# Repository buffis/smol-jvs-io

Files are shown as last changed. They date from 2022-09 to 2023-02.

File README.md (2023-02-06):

# smol-jvs-io

Smol JVS IO is a scoped down JVS I/O board designed to work as a drop-in replacement for arcade stick PCB's, to allow them to interface with JVS hardware. It is not meant to function as a fully functional JVS IO in terms of functionality.

This hardware and software of this board was forked from [td-io](https://github.com/tdaede/td-io) and then heavily scoped down to fit my needs. The td-io firmware is not directly compatible, due to design shortcuts on this board such as removing the shift registers.

At this point, I suppose not much of the td-io hardware schematic is used here any more. The firmware is still a pretty close fork though.

# Features

* JVS IO board interface as one-player device.
* Brook board compatible 20pin connector for hooking up player 1 stick and buttons.
* Upgradeable firmware

# BOM

Note that earlier versions may miss some of these, or have other component identifiers, but overall should be the same.

- U1 ADM3485EARZ-REEL7 or ST3485EBDR (or some other pin compatible one)
- U2 Raspberry Pi Pico
- Q1 AO3400A (Or any similar mosfet)
- D1 BAV99S,115 
- R1 0805 120ohm
- R2 0805 1k ohm
- J1 USBR-B-S-F-O-TH (Digikey: SAM10873-ND)
- J2 JST PH 1x4
- J3 JST PH 1x4
- J4 2.54mm Pinheader 2x10
- J5 JST XH 1x2

# Stuff intentionally not provided

* Player 2 controls
* Chaining other JVS IO boards
* Video/Audio handling
* Analog controls, Mahjong controls...

# Power

Power can either be provided to the micro USB port of the raspberry pi pico, or through the +5V/GND pins of the board.

# Firmware Updates

Flash the Raspberry Pi Pico with new firmware. Make sure stick is not powered from other sources.

# License

CERN-OHL-W

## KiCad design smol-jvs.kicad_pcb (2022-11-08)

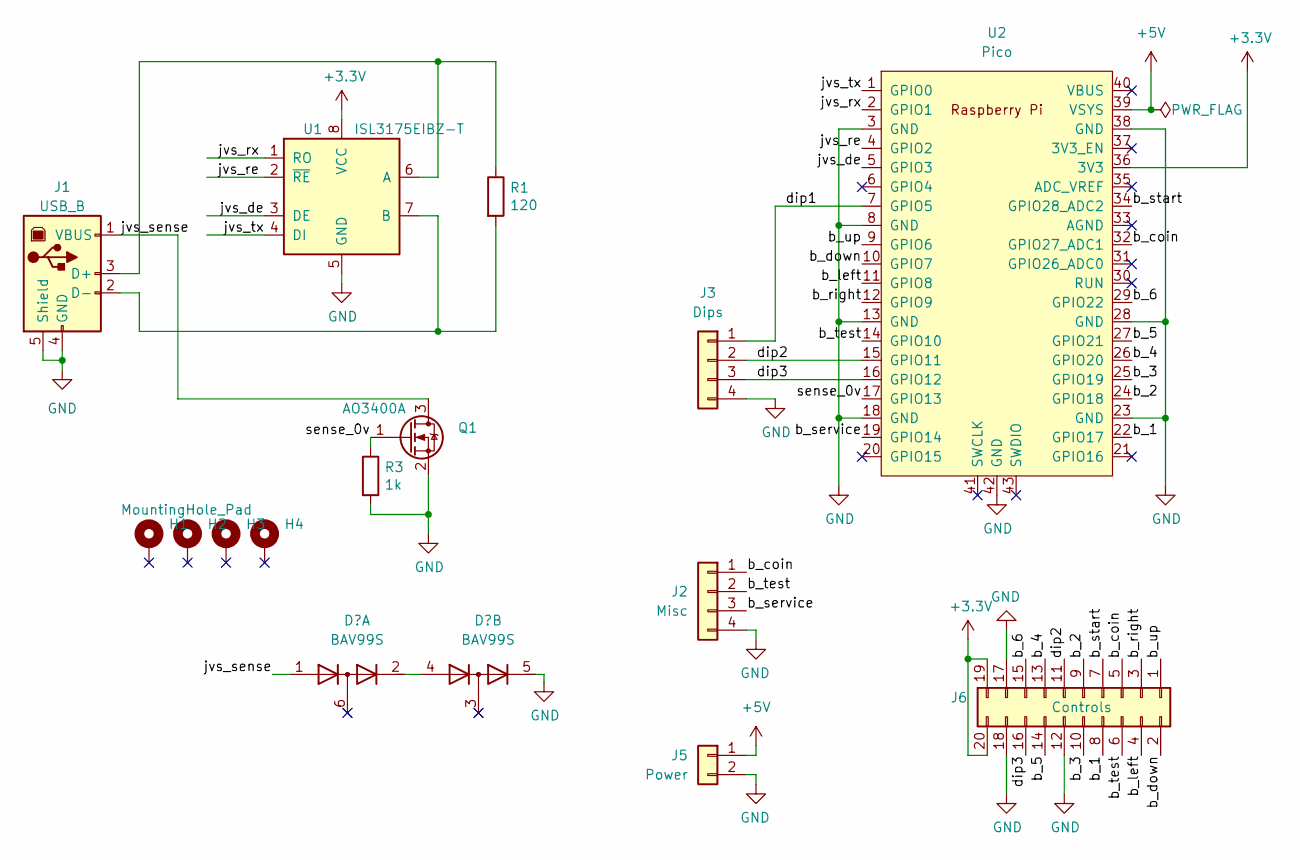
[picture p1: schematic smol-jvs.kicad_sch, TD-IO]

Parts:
H1, H2, H3, H4: MountingHole_Pad; MountingHole_2.5mm_Pad
J1: USB_B; USB_B_OST_USB-B1HSxx_Horizontal; Digikey SAM10873-ND
J2: Misc; JST_PH_B4B-PH-K_1x04_P2.00mm_Vertical
J3: Dips; JST_PH_B4B-PH-K_1x04_P2.00mm_Vertical
J5: Power; JST_XH_B2B-XH-AM_1x02_P2.50mm_Vertical
J6: Controls; PinHeader_2x10_P2.54mm_Vertical
Q1: AO3400A; SOT-23
R1: 120; R_0805_2012Metric; Digikey 13-RT0805FRE07120RLCT-ND
R3: 1k; R_0805_2012Metric; Digikey 311-10.0KCRCT-ND
U1: ISL3175EIBZ-T; SOIC-8_3.9x4.9mm_P1.27mm; Digikey 1016-1150-5-ND
U2: Pico; RPi_Pico_SMD_TH

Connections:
+3V3: J6.19, J6.20, U1.8 (VCC), U2.36 (3V3)
+5V: J5.1, U2.39 (VSYS)
/b_1: J6.8, U2.22 (GPIO17)
/b_2: J6.9, U2.24 (GPIO18)
/b_3: J6.10, U2.25 (GPIO19)
/b_4: J6.13, U2.26 (GPIO20)
/b_5: J6.14, U2.27 (GPIO21)
/b_6: J6.15, U2.29 (GPIO22)
/b_coin: J2.1, J6.5, U2.32 (GPIO27_ADC1)
/b_down: J6.2, U2.10 (GPIO7)
/b_left: J6.4, U2.11 (GPIO8)
/b_right: J6.3, U2.12 (GPIO9)
/b_service: J2.3, U2.19 (GPIO14)
/b_start: J6.7, U2.34 (GPIO28_ADC2)
/b_test: J2.2, J6.6, U2.14 (GPIO10)
/b_up: J6.1, U2.9 (GPIO6)
/dip1: J3.1, U2.7 (GPIO5)
/dip2: J3.2, J6.11, U2.15 (GPIO11)
/dip3: J3.3, J6.16, U2.16 (GPIO12)
/jvs_de: U1.3 (DE), U2.5 (GPIO3)
/jvs_re: U1.2 (~RE), U2.4 (GPIO2)
/jvs_rx: U1.1 (RO), U2.2 (GPIO1)
/jvs_sense: J1.1 (VBUS), Q1.3 (D); also elsewhere on the board
/jvs_tx: U1.4 (DI), U2.1 (GPIO0)
/sense_0v: Q1.1 (G), R3.1, U2.17 (GPIO13)
GND: J1.4 (GND), J1.5 (Shield), J2.4, J3.4, J5.2, J6.12, J6.17, J6.18, Q1.2 (S), R3.2, U1.5 (GND), U2.3 (GND), U2.8 (GND), U2.13 (GND), U2.18 (GND), U2.23 (GND), U2.28 (GND), U2.38 (GND), U2.42 (GND); also elsewhere on the board
unnamed: J1.2 (D-), R1.2, U1.7 (B)
unnamed: J1.3 (D+), R1.1, U1.6 (A)

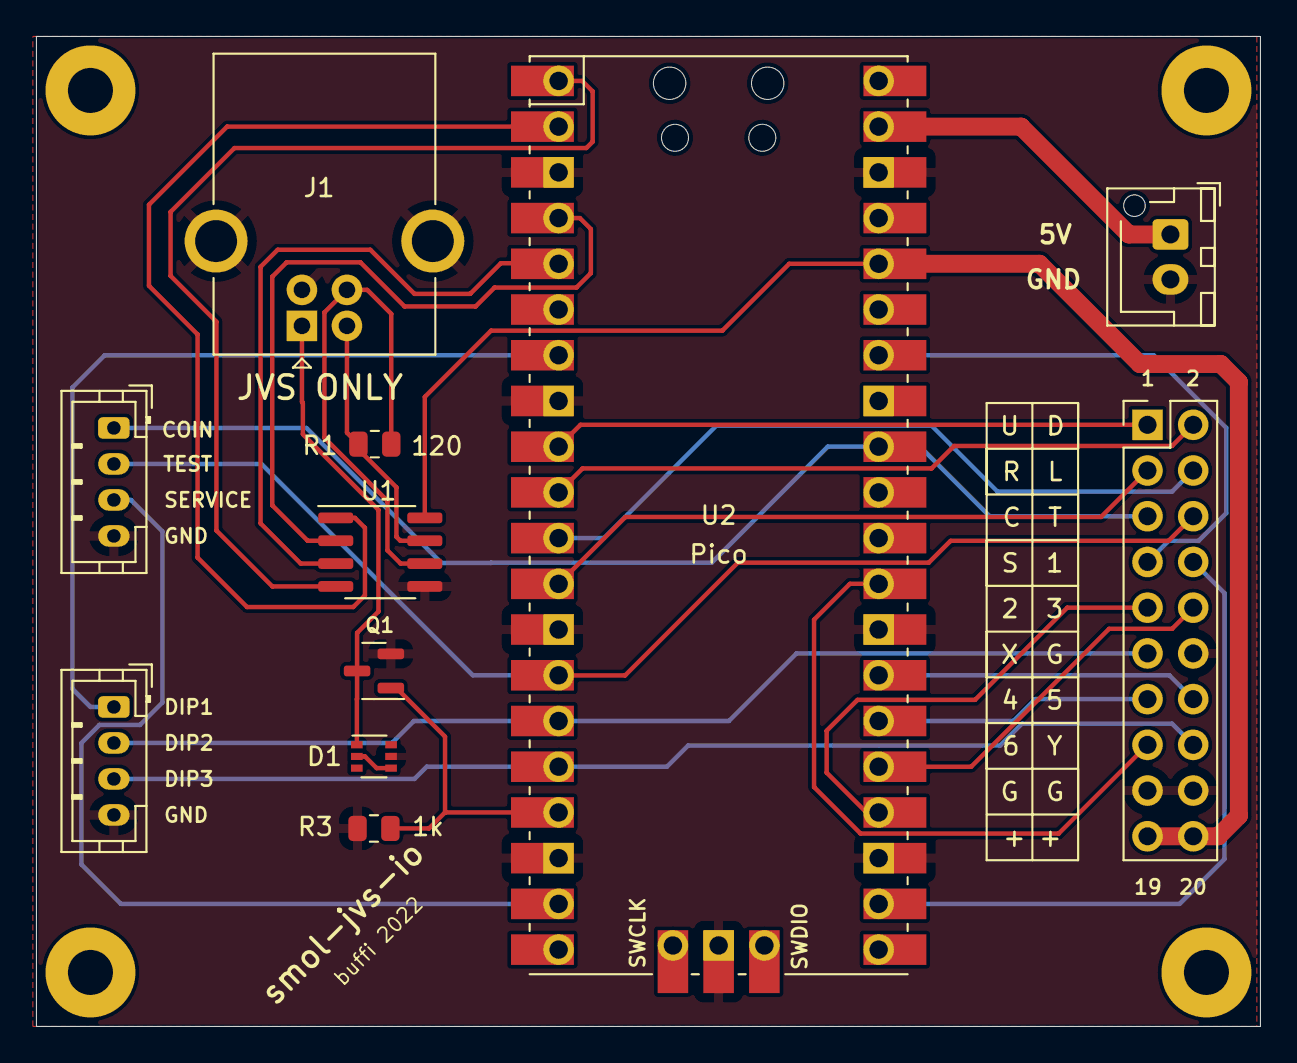
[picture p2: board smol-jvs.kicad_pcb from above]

Board: 2 copper layers, 68.0 x 55.0 mm, 15 parts (0 on the bottom side), 29 nets.

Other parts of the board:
D1: BAV99S; SOT-363_SC-70-6

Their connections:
/jvs_sense: D1.1 (A1); also elsewhere on the board
GND: D1.5 (K4); also elsewhere on the board
unnamed: D1.2 (K2), D1.4 (A3)

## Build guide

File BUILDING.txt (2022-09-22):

# In PowerShell
cd build
cmake -G "NMake Makefiles" ..
nmake

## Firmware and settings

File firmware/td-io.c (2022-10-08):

// Adapted from the https://github.com/tdaede/td-io firmware but scoped down.

#include <stdio.h>
#include "pico/stdlib.h"
#include "hardware/adc.h"
#include <string.h>

const uint PIN_JVS_RE = 2;
const uint PIN_JVS_DE = 3;

const uint PIN_JVS_SENSE_0V = 13;

const uint PIN_JVS_TERMINATION = 15; // TODO: Remove.

const uint PIN_LED_ENUMERATED = PICO_DEFAULT_LED_PIN;
const uint PIN_DIP1 = 11;
const uint PIN_DIP2 = 12;
const uint PIN_DIP3 = 15;

// New pins for direct inputs.
const uint PIN_BTN_TEST = 10;
const uint PIN_BTN_SERVICE = 14;
const uint PIN_BTN_COIN = 27;
const uint PIN_BTN_START = 28;
const uint PIN_JOY_UP = 6;
const uint PIN_JOY_DOWN = 7;
const uint PIN_JOY_LEFT = 8;
const uint PIN_JOY_RIGHT = 9;
const uint PIN_BTN_1 = 17;
const uint PIN_BTN_2 = 18;
const uint PIN_BTN_3 = 19;
const uint PIN_BTN_4 = 20;
const uint PIN_BTN_5 = 21;
const uint PIN_BTN_6 = 22;

const uint8_t JVS_STATUS_GOOD = 1;
const uint8_t JVS_STATUS_UNKNOWN_COMMAND = 2;
const uint8_t JVS_STATUS_CHECKSUM_ERROR = 3;
const uint8_t JVS_STATUS_OVERFLOW = 4;

const uint8_t JVS_REPORT_GOOD = 1;
const uint8_t JVS_REPORT_PARAMETER_INVALID = 3;

const uint8_t JVS_MAX_LEN = 253; // minus two for status and checksum

// global state
uint8_t our_address = 0;
uint64_t last_process_coin = 0;
// signed for underflow checks
int16_t coin_count_p1 = 0;
int16_t coin_count_p2 = 0;
uint8_t prev_coin_p1 = 0;
uint8_t prev_coin_p2 = 0;

#define SR_P1_3 7
#define SR_P2_3 6
#define SR_P1_4 5
#define SR_P2_4 4
#define SR_P1_5 3
#define SR_P2_5 2
#define SR_P1_6 1
#define SR_P2_6 0
#define SR_P1_LEFT 15
#define SR_P2_LEFT 14
#define SR_P1_RIGHT 13
#define SR_P2_RIGHT 12
#define SR_P1_1 11
#define SR_P2_1 10
#define SR_P1_2 9
#define SR_P2_2 8
#define SR_C1 23
#define SR_C2 22
#define SR_P1_START 21
#define SR_P2_START 20
#define SR_P1_UP 19
#define SR_P2_UP 18
#define SR_P1_DOWN 17
#define SR_P2_DOWN 16
#define SR_SERVICE 31
#define SR_TEST 30
#define SR_TILT 29

const uint8_t JVS_COMM_VER = 0x10;
const char id_str[] = "BUFFI;smol-jvs;v1.0;https://github.com/buffis";

const uint8_t input_desc_1coin[] = {
    0x01, 2, 12, 0,
    0x02, 1, 0, 0,
    0x00
};

const uint8_t input_desc_2coin[] = {
    0x01, 2, 12, 0,
    0x02, 2, 0, 0,
    0x00
};

void jvs_sync() {
    uart_putc(uart0, 0xe0);
}

uint8_t jvs_getc() {
    uint8_t c = uart_getc(uart0);
    if (c == 0xd0) {
        c = uart_getc(uart0);
        return c + 1;
    } else {
        return c;
    }
}

void jvs_putc(uint8_t c) {
    if (c == 0xe0) {
        uart_putc(uart0, 0xd0);
        uart_putc(uart0, 0xdf);
    } else if (c == 0xd0) {
        uart_putc(uart0, 0xd0);
        uart_putc(uart0, 0xcf);
    } else {
        uart_putc(uart0, c);
    }
}

void start_transmit() {
    gpio_put(PIN_JVS_RE, 1); // disable receive
    busy_wait_us_32(200);    // 200us min for exa compat
    gpio_put(PIN_JVS_DE, 1); // enable transmitter
}

void stop_transmit() {
    uart_tx_wait_blocking(uart0);
    gpio_put(PIN_JVS_DE, 0); // disable transmitter
    gpio_put(PIN_JVS_RE, 0); // enable receiver
}

void send_message(uint8_t status, uint8_t* m, uint8_t msg_len) {
    start_transmit();
    jvs_sync();
    uint8_t checksum = 0;
    jvs_putc(0);
    checksum += 0;
    jvs_putc(msg_len + 2);
    checksum += msg_len + 2;
    jvs_putc(status);
    checksum += status;
    for (int i = 0; i < msg_len; i++) {
        jvs_putc(m[i]);
        checksum += m[i];
    }
    jvs_putc(checksum);
    stop_transmit();
}

uint32_t read_switches() {
    uint32_t switches = 0;
    switches |= (!gpio_get(PIN_BTN_TEST)) << SR_TEST;
    switches |= (!gpio_get(PIN_BTN_COIN)) << SR_C1;
    switches |= (!gpio_get(PIN_BTN_SERVICE)) << SR_SERVICE;
    switches |= (!gpio_get(PIN_BTN_START)) << SR_P1_START;
    switches |= (!gpio_get(PIN_JOY_UP)) << SR_P1_UP;
    switches |= (!gpio_get(PIN_JOY_DOWN)) << SR_P1_DOWN;
    switches |= (!gpio_get(PIN_JOY_LEFT)) << SR_P1_LEFT;
    switches |= (!gpio_get(PIN_JOY_RIGHT)) << SR_P1_RIGHT;
    switches |= (!gpio_get(PIN_BTN_1)) << SR_P1_1;
    switches |= (!gpio_get(PIN_BTN_2)) << SR_P1_2;
    switches |= (!gpio_get(PIN_BTN_3)) << SR_P1_3;
    switches |= (!gpio_get(PIN_BTN_4)) << SR_P1_4;
    switches |= (!gpio_get(PIN_BTN_5)) << SR_P1_5;
    switches |= (!gpio_get(PIN_BTN_6)) << SR_P1_6;
    return switches;
}

// call periodically with switch read to check level changes of coin input
void process_coin(uint32_t switches) {
    if ((switches >> SR_C1 & 1) && !prev_coin_p1) {
        coin_count_p1++;
        if (coin_count_p1 > 16383) {
            coin_count_p1 = 16383;
        }
    }
    if ((switches >> SR_C2 & 1) && !prev_coin_p2) {
        coin_count_p2++;
        if (coin_count_p2 > 16383) {
            coin_count_p2 = 16383;
        }
    }
    prev_coin_p1 = switches >> SR_C1 & 1;
    prev_coin_p2 = switches >> SR_C2 & 1;
}

int main() {
    stdio_init_all();
    uart_init(uart0, 115200);
    uart_set_translate_crlf(uart0, false);
    gpio_set_function(0, GPIO_FUNC_UART);
    gpio_set_function(1, GPIO_FUNC_UART);
    gpio_init(PIN_JVS_RE);
    gpio_put(PIN_JVS_RE, 0); // enable receiver
    gpio_set_dir(PIN_JVS_RE, GPIO_OUT);
    gpio_init(PIN_JVS_DE);
    gpio_put(PIN_JVS_DE, 0); //disable transmitter
    gpio_set_dir(PIN_JVS_DE, GPIO_OUT);
    gpio_init(PIN_JVS_SENSE_0V);
    gpio_put(PIN_JVS_SENSE_0V, 0);
    gpio_set_dir(PIN_JVS_SENSE_0V, GPIO_OUT);
    gpio_init(PIN_JVS_TERMINATION);
    gpio_put(PIN_JVS_TERMINATION, 1); // disable termination by default
    gpio_set_dir(PIN_JVS_TERMINATION, GPIO_OUT);

    // ui
    gpio_init(PIN_LED_ENUMERATED);
    gpio_put(PIN_LED_ENUMERATED, 0);
    gpio_set_dir(PIN_LED_ENUMERATED, GPIO_OUT);
    gpio_init(PIN_DIP1);
    gpio_set_dir(PIN_DIP1, GPIO_IN);
    gpio_pull_up(PIN_DIP1);

    // Control inputs
    gpio_init(PIN_BTN_TEST);
    gpio_init(PIN_BTN_SERVICE);
    gpio_init(PIN_BTN_COIN);
    gpio_init(PIN_BTN_START);
    gpio_init(PIN_JOY_UP);
    gpio_init(PIN_JOY_DOWN);
    gpio_init(PIN_JOY_LEFT);
    gpio_init(PIN_JOY_RIGHT);
    gpio_init(PIN_BTN_1);
    gpio_init(PIN_BTN_2);
    gpio_init(PIN_BTN_3);
    gpio_init(PIN_BTN_4);
    gpio_init(PIN_BTN_5);
    gpio_init(PIN_BTN_6);
    gpio_set_dir(PIN_BTN_TEST, GPIO_IN);
    gpio_set_dir(PIN_BTN_SERVICE, GPIO_IN);
    gpio_set_dir(PIN_BTN_COIN, GPIO_IN);
    gpio_set_dir(PIN_BTN_START, GPIO_IN);
    gpio_set_dir(PIN_JOY_UP, GPIO_IN);
    gpio_set_dir(PIN_JOY_DOWN, GPIO_IN);
    gpio_set_dir(PIN_JOY_LEFT, GPIO_IN);
    gpio_set_dir(PIN_JOY_RIGHT, GPIO_IN);
    gpio_set_dir(PIN_BTN_1, GPIO_IN);
    gpio_set_dir(PIN_BTN_2, GPIO_IN);
    gpio_set_dir(PIN_BTN_3, GPIO_IN);
    gpio_set_dir(PIN_BTN_4, GPIO_IN);
    gpio_set_dir(PIN_BTN_5, GPIO_IN);
    gpio_set_dir(PIN_BTN_6, GPIO_IN);
    gpio_pull_up(PIN_BTN_TEST);
    gpio_pull_up(PIN_BTN_SERVICE);
    gpio_pull_up(PIN_BTN_COIN);
    gpio_pull_up(PIN_BTN_START);
    gpio_pull_up(PIN_JOY_UP);
    gpio_pull_up(PIN_JOY_DOWN);
    gpio_pull_up(PIN_JOY_LEFT);
    gpio_pull_up(PIN_JOY_RIGHT);
    gpio_pull_up(PIN_BTN_1);
    gpio_pull_up(PIN_BTN_2);
    gpio_pull_up(PIN_BTN_3);
    gpio_pull_up(PIN_BTN_4);
    gpio_pull_up(PIN_BTN_5);
    gpio_pull_up(PIN_BTN_6);

    gpio_put(PIN_JVS_TERMINATION, 0);

    while (true) {
        const uint64_t now = time_us_64();
        if ((now - last_process_coin) > 20000) {
            uint32_t switches = read_switches();
            process_coin(switches);
            last_process_coin = now;
        }

        if (uart_is_readable(uart0) && uart_getc(uart0) == 0xe0) {
            uint8_t our_checksum = 0;
            uint8_t node_num = jvs_getc();
            if (!((node_num == 0xff) || ((our_address == node_num) && (our_address != 0)))) {
                continue;
            }
            our_checksum += node_num;
            uint8_t length = jvs_getc();
            our_checksum += length;
            uint8_t msg_length = length - 1;
            uint8_t message[256];
            for (int i = 0; i < msg_length; i++) {
                uint8_t c = jvs_getc();
                our_checksum += c;
                message[i] = c;
            }
            uint8_t msg_send[256*2]; // a few bytes to spare for easier overflow checking
            int o = 0;
            uint8_t status = JVS_STATUS_GOOD;
            uint8_t their_checksum = jvs_getc();
            if (our_checksum == their_checksum) {
                int i = 0;
                while (i < msg_length) {
                    if ((msg_length - i) >= 2 && message[i] == 0xf0 && message[i+1] == 0xd9) {
                        printf("N: %02x Reset\n", node_num);
                        our_address = 0;
                        gpio_put(PIN_JVS_SENSE_0V, 0);
                        gpio_put(PIN_LED_ENUMERATED, 0);
                        i += 2;
                    } else if ((msg_length - i) >= 2 && message[i] == 0xf1) {
                        uint8_t node_id = message[i+1];
                        i += 2;
                        printf("Assign node id N: %02x\n", node_id);
                        if (our_address == 0) {
                            printf("Assigning our address\n");
                            our_address = node_id;
                            msg_send[o] = JVS_REPORT_GOOD;
                            o++;
                            gpio_put(PIN_JVS_SENSE_0V, 1);
                            gpio_put(PIN_LED_ENUMERATED, 1);
                        } else {
                            printf("We are not currently last in the chain, skipping assignment\n");
                        }
                    } else if ((msg_length - i) >= 1 && message[i] == 0x10) {
                        i++;
                        printf("Got ID code request\n");
                        msg_send[o] = JVS_REPORT_GOOD;
                        o++;
                        strcpy((char*)&msg_send[o], id_str);
                        o += strlen(id_str) + 1;
                    } else if ((msg_length - i) >= 1 && message[i] == 0x11) {
                        i++;
                        printf("Got revision request\n");
                        msg_send[o] = JVS_REPORT_GOOD;
                        o++;
                        msg_send[o] = 0x13;
                        o++;
                    } else if ((msg_length - i) >= 1 && message[i] == 0x12) {
                        i++;
                        printf("Got video revision request\n");
                        msg_send[o] = JVS_REPORT_GOOD;
                        o++;
                        msg_send[o] = 0x30;
                        o++;
                    } else if ((msg_length - i) >= 1 && message[i] == 0x13) {
                        i++;
                        printf("Got comm revision request\n");
                        msg_send[o] = JVS_REPORT_GOOD;
                        o++;
                        msg_send[o] = JVS_COMM_VER;
                        o++;
                    } else if ((msg_length - i) >= 1 && message[i] == 0x14) {
                        i++;
                        printf("Got input descriptor request\n");
                        msg_send[o] = JVS_REPORT_GOOD;
                        o++;
                        if (!gpio_get(PIN_DIP1)) {
                            memcpy(&msg_send[o], input_desc_1coin, sizeof(input_desc_1coin));
                            o += sizeof(input_desc_1coin);
                        } else {
                            memcpy(&msg_send[o], input_desc_2coin, sizeof(input_desc_2coin));                        o += sizeof(input_desc_2coin);
                        }
                    } else if ((msg_length - i) >= 1 && message[i] == 0x15) {
                        i++;
                        printf("Got main board ID: ");
                        while (i < msg_length) {
                            char c = message[i];
                            i++;
                            if (c == 0) break;
                            putchar(message[i]);
                        }
                        printf("\n");
                        msg_send[o] = JVS_REPORT_GOOD;
                        o++;
                    } else if ((msg_length - i) >= 3 && message[i] == 0x20) {
                        int num_players = message[i+1];
                        int bytes_per_player = message[i+2];
                        i += 3;
                        if (o + num_players*bytes_per_player >= JVS_MAX_LEN) {
                            printf("JVS response overflow!\n");
                            status = JVS_STATUS_OVERFLOW;
                            break;
                        }
                        msg_send[o] = JVS_REPORT_GOOD;
                        o++;
                        uint32_t switches = read_switches();
                        if ((now - last_process_coin) > 12000) {
                            process_coin(switches);
                            last_process_coin = now;
                        }
                        // Cool stuff here.
                        msg_send[o] = !gpio_get(PIN_BTN_TEST) << 7;
                        o++;
                        //printf("Got switch request for %02x players\n", num_players);
                        for (int player = 0; player < num_players; player++) {
                            for (int byte = 0; byte < bytes_per_player; byte++) {
                                uint8_t b = 0;
                                if ((player == 0) && (byte == 0)) {
                                    b = ((switches >> SR_P1_2) & 1) << 0
                                        | ((switches >> SR_P1_1) & 1) << 1
                                        | ((switches >> SR_P1_RIGHT) & 1) << 2
                                        | ((switches >> SR_P1_LEFT) & 1) << 3
                                        | ((switches >> SR_P1_DOWN) & 1) << 4
                                        | ((switches >> SR_P1_UP) & 1) << 5
                                        | ((switches >> SR_SERVICE) & 1) << 6
                                        | ((switches >> SR_P1_START) & 1) << 7;
                                } else if ((player == 0) && (byte == 1)) {
                                    b = ((switches >> SR_P1_6) & 1) << 4
                                        | ((switches >> SR_P1_5) & 1) << 5
                                        | ((switches >> SR_P1_4) & 1) << 6
                                        | ((switches >> SR_P1_3) & 1) << 7;
                                } else if ((player == 1) && (byte == 0)) {
                                    b = ((switches >> SR_P2_2) & 1) << 0
                                        | ((switches >> SR_P2_1) & 1) << 1
                                        | ((switches >> SR_P2_RIGHT) & 1) << 2
                                        | ((switches >> SR_P2_LEFT) & 1) << 3
                                        | ((switches >> SR_P2_DOWN) & 1) << 4
                                        | ((switches >> SR_P2_UP) & 1) << 5
                                        | ((switches >> SR_P2_START) & 1) << 7;
                                } else if ((player == 1) && (byte == 1)) {
                                    b = ((switches >> SR_P2_6) & 1) << 4
                                        | ((switches >> SR_P2_5) & 1) << 5
                                        | ((switches >> SR_P2_4) & 1) << 6
                                        | ((switches >> SR_P2_3) & 1) << 7;
                                }
                                msg_send[o] = b;
                                o++;
                            }
                        }
                    } else if ((msg_length - i) >= 2 && message[i] == 0x21) {
                        int slots = message[i+1];
                        i += 2;
                        if (o + slots*2 >= JVS_MAX_LEN) {
                            printf("JVS response overflow!\n");
                            status = JVS_STATUS_OVERFLOW;
                            break;
                        }
                        msg_send[o] = JVS_REPORT_GOOD;
                        o++;
                        //printf("Got coin slot request for %02x slots\n", slots);
                        for (int slot = 0; slot < slots; slot++) {
                            if (slot == 0) {
                                msg_send[o] = coin_count_p1 >> 8;
                                msg_send[o+1] = coin_count_p1 & 0xFF;
                            } else if (slot == 1) {
                                msg_send[o] = coin_count_p2 >> 8;
                                msg_send[o+1] = coin_count_p2 & 0xFF;
                            } else {
                                msg_send[o] = 0x80;
                                msg_send[o+1] = 0x00;
                            }
                            o += 2;
                        }
                    } else if ((msg_length - i) >= 4 && message[i] == 0x30) {
                        uint8_t slot = message[i+1];
                        uint16_t amount = (message[i+2] << 8) + message[i+3];
                        i += 4;
                        printf("Decrement coin counter %d by %d\n", (int)slot, (int)amount);
                        if (amount > 16383) {
                            amount = 16383;
                            printf("Capped to 16383\n");
                        }
                        if (slot == 1) {
                            msg_send[o] = JVS_REPORT_GOOD;
                            coin_count_p1 -= amount;
                            if (coin_count_p1 < 0) {
                                coin_count_p1 = 0;
                            }
                        } else if (slot == 2) {
                            msg_send[o] = JVS_REPORT_GOOD;
                            coin_count_p2 -= amount;
                            if (coin_count_p2 < 0) {
                                coin_count_p2 = 0;
                            }
                        } else {
                            printf("Invalid coin counter slot\n");
                            msg_send[o] = JVS_REPORT_PARAMETER_INVALID;
                        }
                        o++;
                    } else if ((msg_length - i) >= 4 && message[i] == 0x35) {
                        uint8_t slot = message[i+1];
                        uint16_t amount = (message[i+2] << 8) + message[i+3];
                        i += 4;
                        printf("Increment coin counter %d by %d\n", (int)slot, (int)amount);
                        if (amount > 16383) {
                            amount = 16383;
                            printf("Capped to 16383\n");
                        }
                        if (slot == 1) {
                            msg_send[o] = JVS_REPORT_GOOD;
                            coin_count_p1 += amount;
                            if (coin_count_p1 > 16383) {
                                coin_count_p1 = 16383;
                            }
                        } else if (slot == 2) {
                            msg_send[o] = JVS_REPORT_GOOD;
                            coin_count_p2 += amount;
                            if (coin_count_p2 > 16383) {
                                coin_count_p2 = 16383;
                            }
                        } else {
                            printf("Invalid coin counter slot\n");
                            msg_send[o] = JVS_REPORT_PARAMETER_INVALID;
                        }
                        o++;
                    } else {
                        printf("Unsupported message: N: %02x L: %02x M: ", node_num, msg_length);
                        for (int j = 0; j < msg_length; j++) {
                            printf("%02x", message[j]);
                        }
                        printf("\n");
                        status = JVS_STATUS_UNKNOWN_COMMAND;
                        break;
                    }
                    if (o >= JVS_MAX_LEN) {
                        printf("JVS response overflow!\n");
                        status = JVS_STATUS_OVERFLOW;
                        break;
                    }
                }
                fflush(stdout);
                if ((o > 0) || (status != JVS_STATUS_GOOD)) {
                    send_message(status, msg_send, o);
                }
            } else {
                printf("Checksum mismatch: theirs: %02x ours: %02x\n", their_checksum, our_checksum);
                status = JVS_STATUS_CHECKSUM_ERROR;
                send_message(status, msg_send, 0);
            }
        }
    }
    return 0;
}

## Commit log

2022-09-19 Cleaned up pcb
    [td-io.kicad_pcb, td-io.kicad_sch]
2022-09-19 Minor fixes
    [td-io.kicad_pcb, td-io.kicad_sch]
2022-09-20 Minor cleanup
    [td-io.kicad_sch]
2022-10-07 many minor changes
    [td-io.kicad_pcb, td-io.kicad_sch]
2022-10-08 misc stuff
    [td-io.kicad_pcb, td-io.kicad_sch]
2022-10-08 rename to smol-jvs
    [smol-jvs.kicad_pcb, smol-jvs.kicad_sch]
2022-10-08 Fix name of IO
    [td-io.c]
2022-10-09 New gerbers
    [smol-jvs-B_Cu.gbr, smol-jvs-B_Mask.gbr, smol-jvs-B_Paste.gbr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]
2022-10-12 new gerbers and minor updates
    [smol-jvs-B_Cu.gbr, smol-jvs-B_Mask.gbr, smol-jvs-B_Paste.gbr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]
2022-11-08 Go back to using diodes for sense again
    [smol-jvs.kicad_pcb, smol-jvs.kicad_sch]
2023-02-06 Minor pcb updates + BOM
    [smol-jvs.kicad_sch]
